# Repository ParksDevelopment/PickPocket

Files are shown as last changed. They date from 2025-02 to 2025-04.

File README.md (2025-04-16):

# 2Pocket

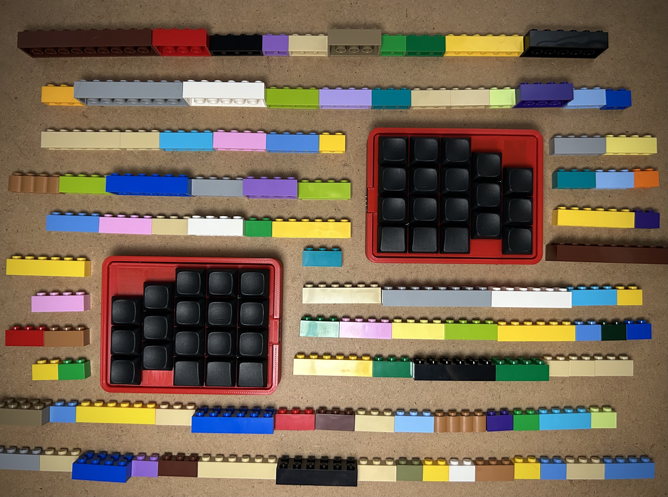
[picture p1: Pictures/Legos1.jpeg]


[Introduction](#Introduction)

[Info and Production](#Production)

[PCB](#PCB)

[Firmware](#Firmware)

[Case](#Case)

[Overview](#Overview)

## Introduciton

The PickPocket is a revamped version of my contest entry keyboard the [2Pocket](https://github.com/ParksDevelopment/2Pocket/tree/main). When I started making the list of changes I wanted to make it became clear to me I wanted to make a new project from the ground up, so despite thier similarities the PickPocket is a brand new project with the following features and changes from 2Pocket

Features
- 36 Kailh Choc V1 Low Profile Hot swap sockets (Using [Nocturnals](https://lowprokb.ca/collections/switches/products/ambients-silent-choc-switches) switches for all pictures)
- Bluetooth support between halves and computer
- Powered by 2 (XIAO nRF52840)[https://wiki.seeedstudio.com/XIAO_BLE/]
- 2 3.7V 1100 mAh batteries Charged through the USB C port on the back of each board
- ZMK and KMK compatibility tested
- Single reversible PCB for cheaper manufacturing
- Pass Through charging through magnetic push pins. Plugging in the left half and connecting the boards will charge both of them.
- Still small enough for your pockets!

Changes from 2Pocket
- Removed the pedometer. This was adding a few dollars per board and made the wiring for a reversable pcb more than I wanted to deal with
- Removed the 2 additional buttons. they were for pedometer controls primarily 
- Increased size for better case design. From 190mm x 74.8mm x 22mm to 207mm x 79mm x 23.5mm

The main goal of all these changes was to make something I could bring into work, was sturdy enough to be moved around, and solved my biggest frusteration with split keyboards which is charging them.

## Production

This project is both not for a contest and much simpler so I will briefly touch on the production and related information. Below is the Item list

| Part Name  | Quantity | Solder by hand |
|---|---|---|
| 1N4148 Diode | 38| NO|
| 2 pin Jst socket | 2| YES|
| Choc hotswap sockets | 36| YES|
| Xiao NRF52840 | 2| YES|
| EEMB Lithium Polymer Battery 3.7V 1100mAh | 2| DNA|
|Magnetic Connector - Right Angle Three Contact Pins | 2| YES|

## PCB

The PCB has a footprint of 95mm x 71.5mm x 1.6mm and is reversable so the cost of production is quite small. It also features 4 mounting holes that are small enough to fit between the keys and are intended for M2 screws. Some things to note if you plan on making one is that to accomadate for the small size the parts that are hand soldered will always be on the bottom of their respective side. This means that you will want to put the micro controller on the bottom of each board. The wiring will work with it on the top but it will overlap with some of the keys. Same goes for the magnetic push pins. There are also 2 spots for the jst connectors. this is so they can be mounted on the bottom and still allow for the same ground power set up of a battery.

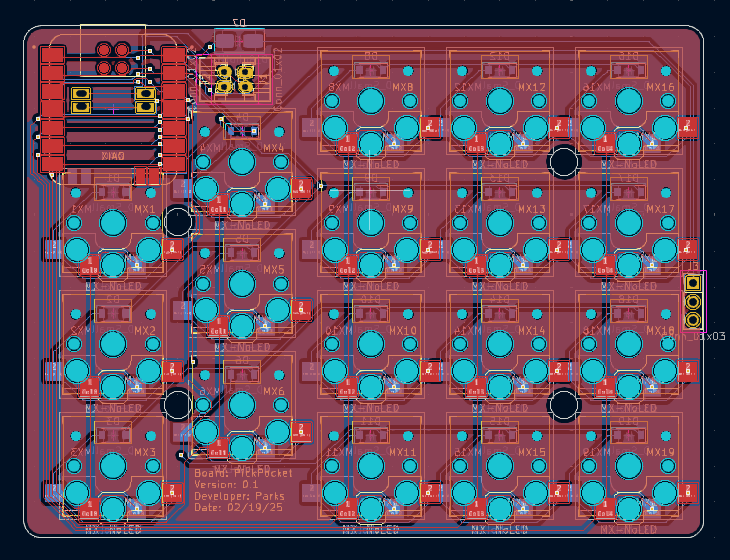
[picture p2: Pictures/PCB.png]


## Firmware

Due to the lack of a ADXL345 there is not much need for any firmware changes. Anything that works with a Xiao NRF52840 will work with this as long at it has bluetooth support

There are 2 pins, 4 and 5, which are also the I2C pins that go unused, for now. if you want to add the pedometer back in there is room for it through these.
Row Pins: 0,1,2,3
Column Pins: 6,7,8,9,10

## Case

The Case isn't anything special but I am happy with how it came out. Because of the extra space I have not working in the constraints of the contest I was able to get something a lot more sturdy. It is reversable like the board so 2 pieces each, a plate and the bottom. It also requires some threaded inserts but those can be easily removed. As it stands only the left side has a reset button.

| Part Name  | Quantity | Link  |
|---|---|---|
| M2 threaded inserts| 4| [Link](https://www.amazon.com/dp/B0DGP6FH5H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)|
| M2 Standoff and screws| 4| [Link](https://www.amazon.com/M2-Motherboard-Standoffs-Male-Female-Electronic/dp/B0BP6MT7RP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)

Much happier with the case this time around and while it still has quirks I don't feel the need to change it that much. I am using the keyboard to go to work and I never have any concerns throwing it in a bag.

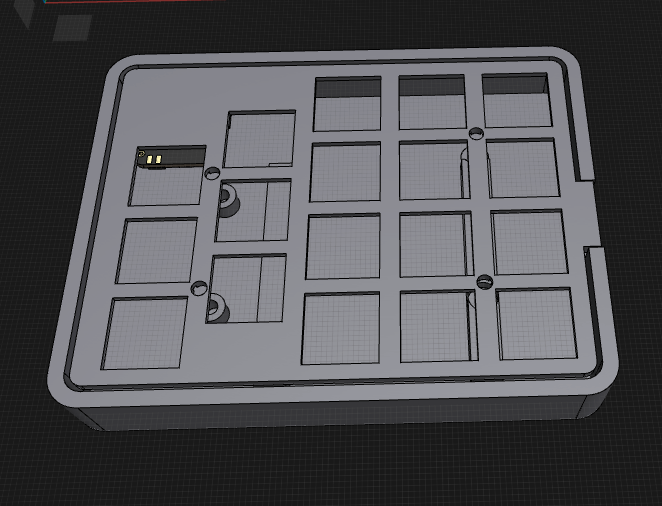
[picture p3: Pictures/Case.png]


## Overview

I have been happy with this redesign, while it is sad to lose the ADXL345, since there is a lot I was hoping to do with it and it was one of the more unique parts of the first board, it definetly made the project more streamlined, cheaper, and approachable. The pass through charging can not be understated for the impact it has made on my desire to make the board. The whole thing having "one" battery makes it much easier to work with. This is probably my last project with this form factor for a while, not because I don't like it but because I nailed what I was looking for with this one and don't have a whole lot I would want to change. Was told by multiple people it looks like legos, ie the photos.

If you enjoyed or found and of the information helpful consider [Buying me a coffee](https://buymeacoffee.com/parks) to keep working on projects like this!

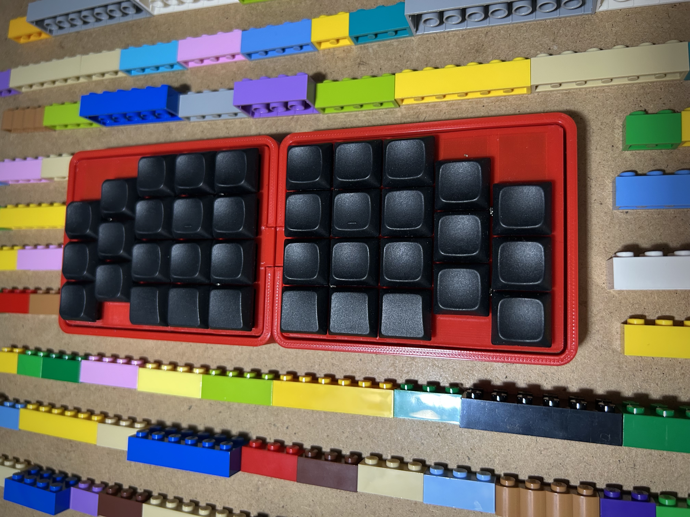
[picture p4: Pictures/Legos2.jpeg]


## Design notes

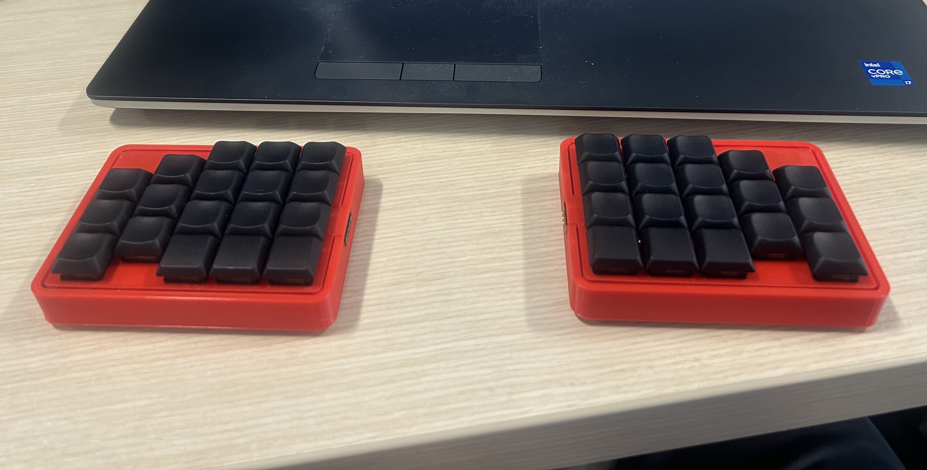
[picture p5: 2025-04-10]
Pictures/Work.jpeg

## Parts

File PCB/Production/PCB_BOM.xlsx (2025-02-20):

Comment | Designator | Footprint
D_Small | D11,D10,D2,D13,D19,D16,D5,D12,D15,D14,D1,D8,D18,D6,D4,D3,D9,D17 | D_SOD-123
D_Schottky | D7 | D_SMA

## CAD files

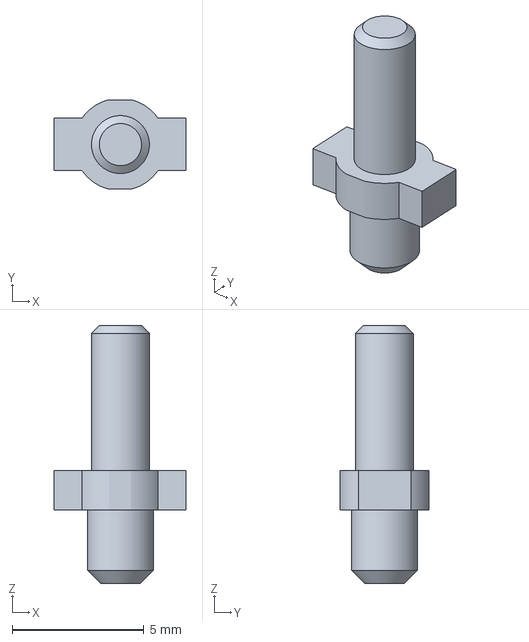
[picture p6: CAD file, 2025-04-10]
Case/PickPocketReset.3mf
5.00 x 3.39 x 9.80 mm

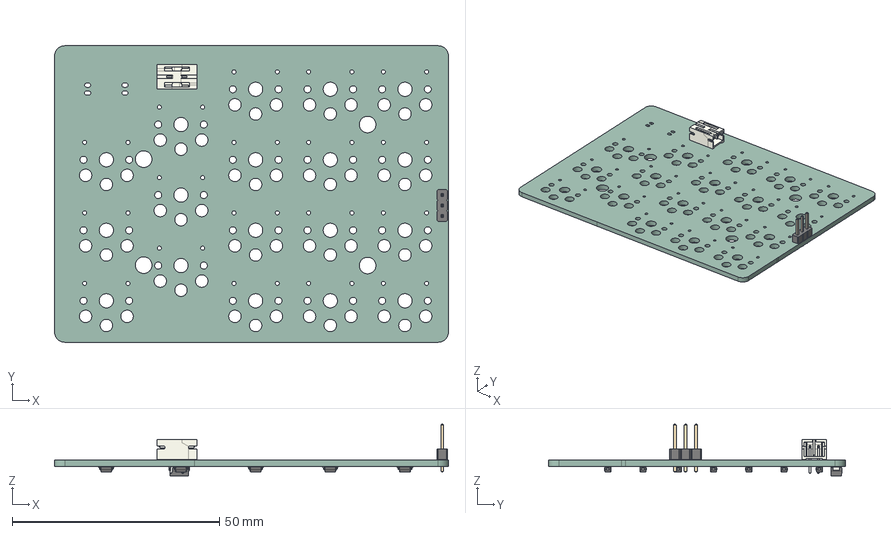
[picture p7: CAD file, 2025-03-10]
PCB/PCB.step
95.0 x 71.5 x 12.5 mm
PinHeader_1x03_P254mm_Vertical
JST_S2B_PH_K x 2
D_SOD_123 x 18
D_SMA
PCB_PCB

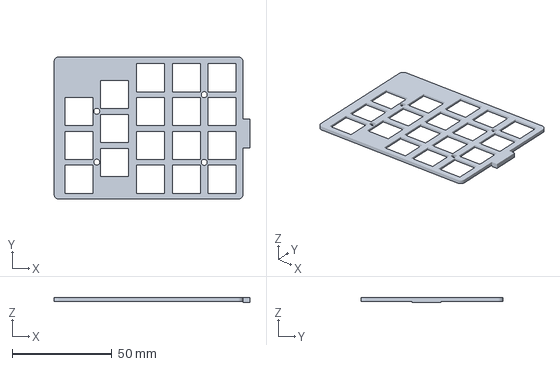
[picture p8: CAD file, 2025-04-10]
Case/PickPocketPlate.3mf
98.5 x 71.5 x 2.60 mm

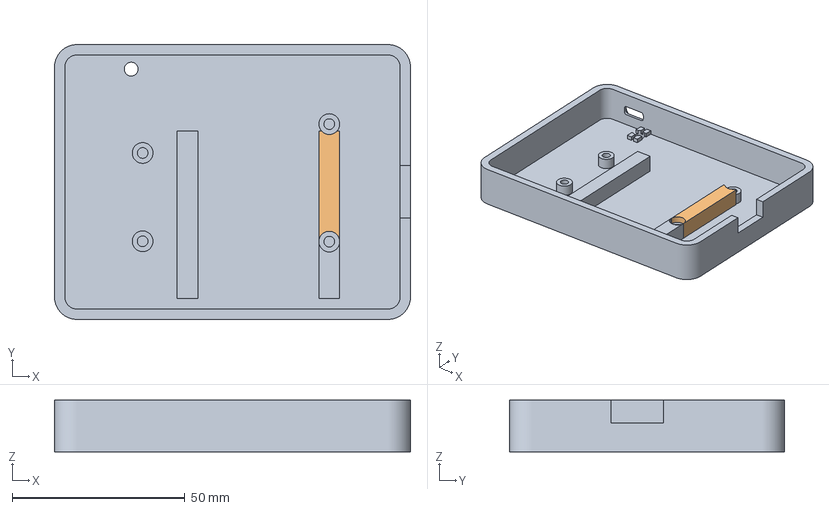
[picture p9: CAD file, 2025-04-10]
Case/PickPocketBase.3mf
103.0 x 79.5 x 15.0 mm

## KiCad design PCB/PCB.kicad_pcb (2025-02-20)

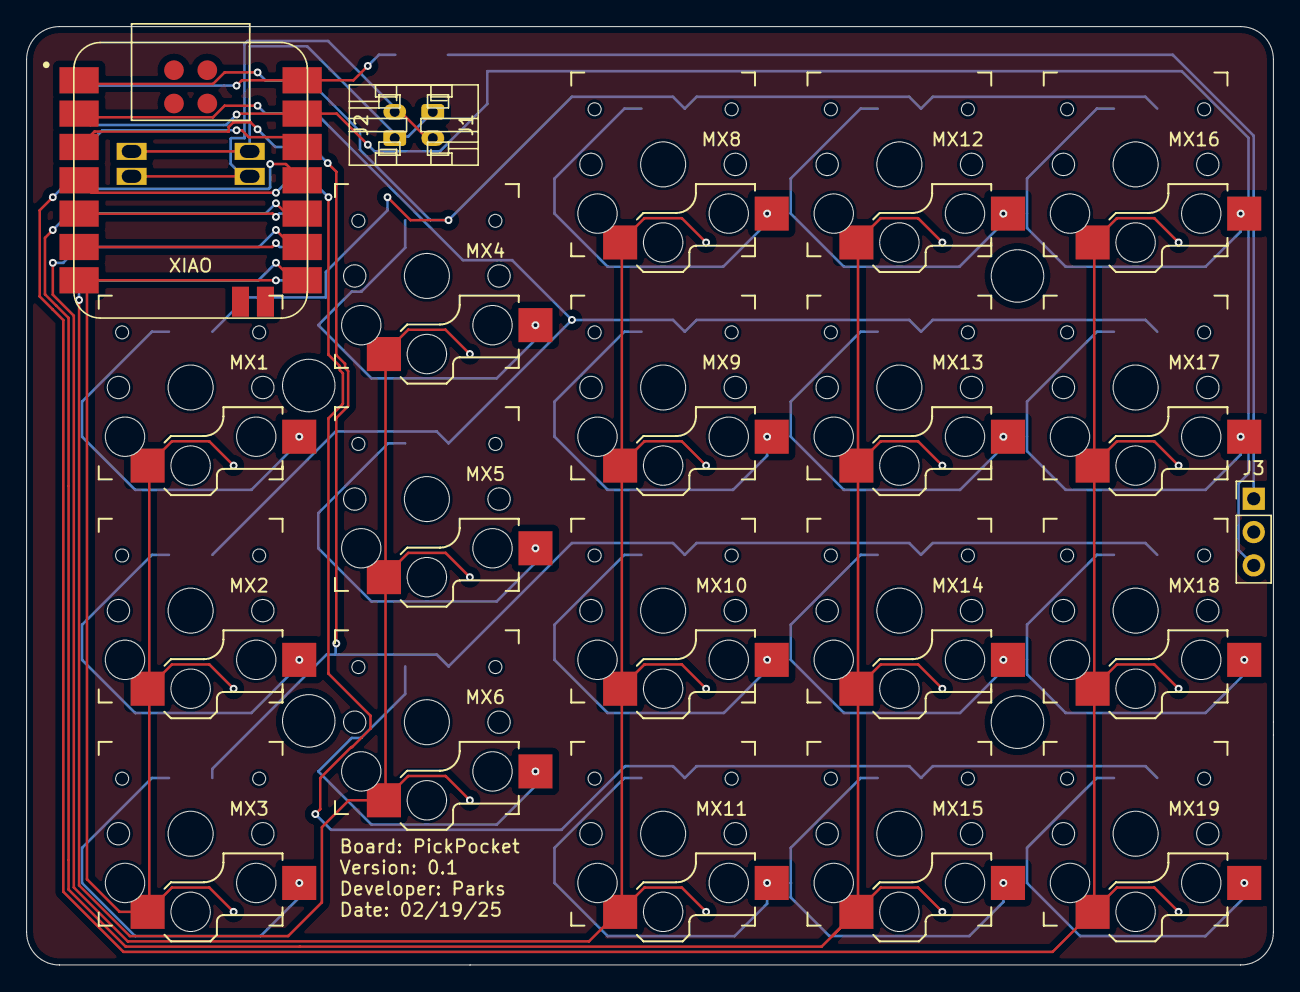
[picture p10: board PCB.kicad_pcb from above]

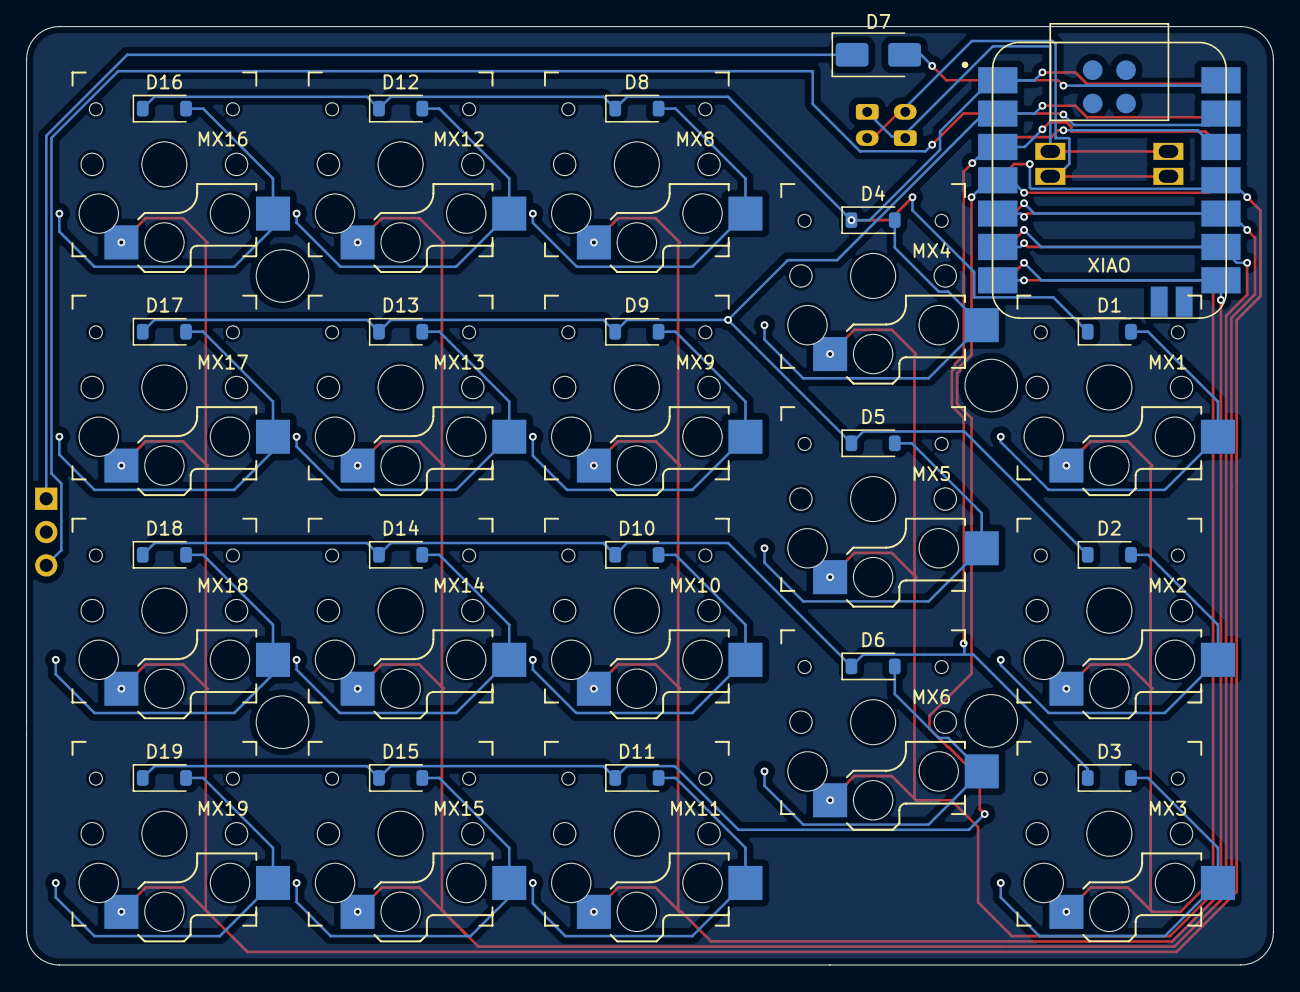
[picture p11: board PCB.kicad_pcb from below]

Board: 2 copper layers, 95.0 x 71.5 mm, 42 parts (20 on the bottom side), 35 nets.

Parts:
D1, D2, D3, D4, D5, D6, D8, D9, D10, D11, D12, D13, D14, D15, D16, D17, D18, D19: D_Small; D_SOD-123
D7: D_Schottky; D_SMA
J1, J2: Conn_01x02; JST_PH_S2B-PH-K_1x02_P2.00mm_Horizontal
J3: Conn_01x03; PinHeader_1x03_P2.54mm_Vertical
MX1, MX2, MX3, MX4, MX5, MX6, MX8, MX9, MX10, MX11, MX12, MX13, MX14, MX15, MX16, MX17, MX18, MX19: MX-NoLED; Kailh_socket_PG1350_reversible
U1, U2: Seeed Studio XIAO nRF52840; XIAO-nRF52840-Sense-14P-2.54-21X17.8MM

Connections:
+3.3V: U1.12 (3V3), U2.12 (3V3)
+5V: D7.2 (A), U1.14 (5V), U2.14 (5V)
/Bat+: J1.2, J2.2, U1.22 (BAT+), U2.22 (BAT+)
/Bat-: J1.1, J2.1, U1.21 (BAT-), U2.21 (BAT-)
/Col0: MX1.1 (COL), MX2.1 (COL), MX3.1 (COL), U1.7 (P1.11_D6_TX), U2.7 (P1.11_D6_TX)
/Col1: MX4.1 (COL), MX5.1 (COL), MX6.1 (COL), U1.8 (P1.12_D7_RX), U2.8 (P1.12_D7_RX)
/Col2: MX8.1 (COL), MX9.1 (COL), MX10.1 (COL), MX11.1 (COL), U1.9 (P1.13_D8_SCK), U2.9 (P1.13_D8_SCK)
/Col3: MX12.1 (COL), MX13.1 (COL), MX14.1 (COL), MX15.1 (COL), U1.10 (P1.14_D9_MISO), U2.10 (P1.14_D9_MISO)
/Col4: MX16.1 (COL), MX17.1 (COL), MX18.1 (COL), MX19.1 (COL), U1.11 (P1.15_D10_MOSI), U2.11 (P1.15_D10_MOSI)
/Row0: D1.1 (K), D4.1 (K), D8.1 (K), D12.1 (K), D16.1 (K), U1.1 (P0.02_A0_D0), U2.1 (P0.02_A0_D0)
/Row1: D2.1 (K), D5.1 (K), D9.1 (K), D13.1 (K), D17.1 (K), U1.2 (P0.03_A1_D1), U2.2 (P0.03_A1_D1)
/Row2: D3.1 (K), D6.1 (K), D10.1 (K), D14.1 (K), D18.1 (K), U1.3 (P0.28_A2_D2), U2.3 (P0.28_A2_D2)
/Row3: D11.1 (K), D15.1 (K), D19.1 (K), U1.4 (P0.29_A3_D3), U2.4 (P0.29_A3_D3)
/temp1: U1.5 (P0.04_A4_D4_SDA), U2.5 (P0.04_A4_D4_SDA)
/temp2: U1.6 (P0.05_A5_D5_SCL), U2.6 (P0.05_A5_D5_SCL)
GND: J3.3, U1.13 (GND), U2.13 (GND)
unnamed: D1.2 (A), MX1.2 (ROW)
unnamed: D2.2 (A), MX2.2 (ROW)
unnamed: D3.2 (A), MX3.2 (ROW)
unnamed: D4.2 (A), MX4.2 (ROW)
unnamed: D5.2 (A), MX5.2 (ROW)
unnamed: D6.2 (A), MX6.2 (ROW)
unnamed: D7.1 (K), J3.1
unnamed: D8.2 (A), MX8.2 (ROW)
unnamed: D9.2 (A), MX9.2 (ROW)
unnamed: D10.2 (A), MX10.2 (ROW)
unnamed: D11.2 (A), MX11.2 (ROW)
unnamed: D12.2 (A), MX12.2 (ROW)
unnamed: D13.2 (A), MX13.2 (ROW)
unnamed: D14.2 (A), MX14.2 (ROW)
unnamed: D15.2 (A), MX15.2 (ROW)
unnamed: D16.2 (A), MX16.2 (ROW)
unnamed: D17.2 (A), MX17.2 (ROW)
unnamed: D18.2 (A), MX18.2 (ROW)
unnamed: D19.2 (A), MX19.2 (ROW)

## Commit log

2025-02-20 pcb v0.1
    [PCB-B_Cu.gbr, PCB-B_Mask.gbr, PCB-B_Paste.gbr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]
2025-04-10 updates made to the case
    [PickPocketBase.3mf, PickPocketPlate.3mf, PickPocketReset.3mf]
